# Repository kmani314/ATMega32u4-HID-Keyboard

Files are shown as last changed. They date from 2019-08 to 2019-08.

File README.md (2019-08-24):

## ATMega32u4 HID Keyboard
###### Board Project 2019 - Krishna Mani
This is software for ATMega32u4 or compatible AVR hardware USB chips that implements a standard-complying HID keyboard using only AVR-LIBC.

I used these for reference when coding:

1. https://www.avrfreaks.net/forum/usb-initialization-problem
2. https://www.pjrc.com/teensy/usb_keyboard.html
3. https://www.usb.org/sites/default/files/documents/hid1_11.pdf
4. https://www.avrfreaks.net/forum/help-properly-initializing-usb-hardware-atmega32u4
5. https://www.beyondlogic.org/usbnutshell/usb1.shtml
6. http://ww1.microchip.com/downloads/en/devicedoc/atmel-7766-8-bit-avr-atmega16u4-32u4_datasheet.pdf
7. https://github.com/arduino/ArduinoCore-avr/blob/master/cores/arduino/USBCore.cpp
8. http://sdphca.ucsd.edu/lab_equip_manuals/usb_20.pdf

Finished Board:

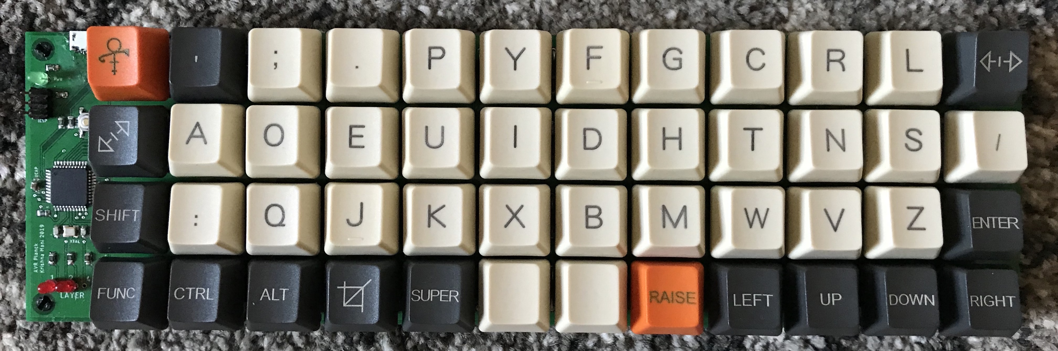
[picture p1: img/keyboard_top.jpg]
Finished Board


### Hardware

##### Microcontroller
The ATMega32u4 controls the scanning matrix and the USB interface. I chose it because of its hardware USB interface and because it has enough I/O pins to support the whole keyboard without needing any multiplexing. It also has enough flash and SRAM for storing layouts. The 32u4 on the keyboard runs at 16mHz from an external crystal oscillator with 22pF load capacitors. It is powered directly from the USB lines with filtering capacitors.
##### PCBs
Initially, I needed to test the main microcontroller circuit of the keyboard to ensure that it worked and that the USB worked, because I had developed on an Arduino Leonardo. (boards/ATMegaTestingBoard.brd)

##### ATMega32u4 Circuit
The portion of the board for the ATMega32u4 is fairly standard for this chip and is similar to the Arduino Leonardo, excluding the power regulators. It consists of the chip, the oscillator and load caps, the power and layer leds, the reset switch, the USB connector and data resistors, the ICSP pins, and the filtering caps on the underside of the board.

Top / Bottom (boards/Keyboard.brd):

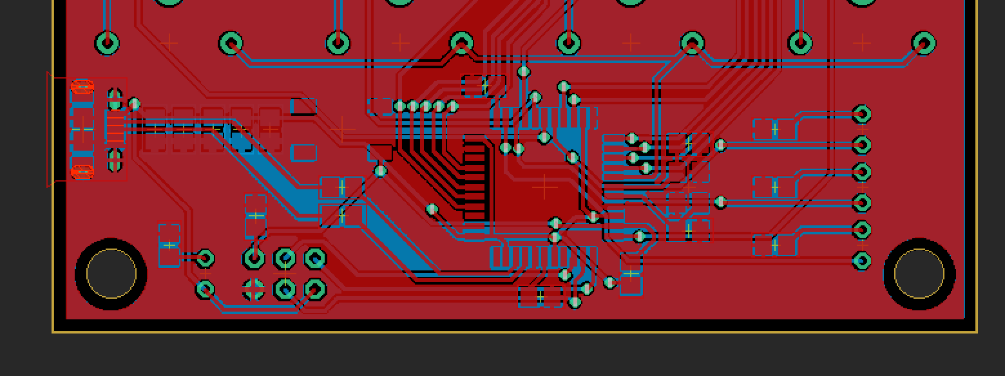
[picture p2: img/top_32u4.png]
32u4 Top


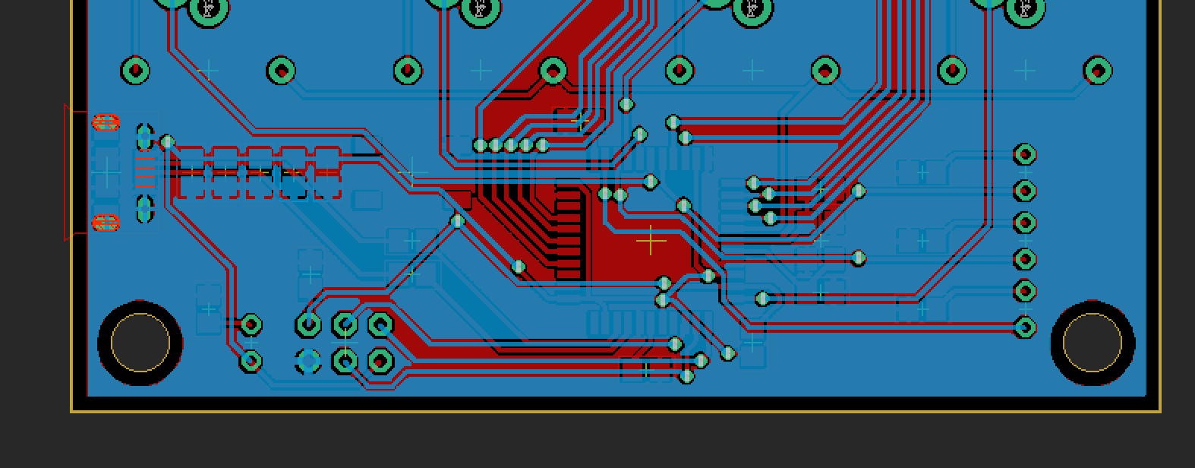
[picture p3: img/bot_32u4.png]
32u4 Bottom


The rest of the board is the scanning matrix. The rows and columns use up the majority of the I/O on the chip.
The matrix is standard for a keyboard - one pin of each switch in a column is connected through a diode to every other one in the column. Then, the remaining pin in each switch is common with the row. I used through hole diodes because they are much easier to solder. The switches are standard mechanical keyboard switches, and the footprints are from here: https://github.com/mknyszek/gateron-eagle
To read the matrix, the row pins are pulled high through internal pull-up resistors. One column at a time is set low, so that a pressed key would pull the row pin low, signaling a key press at the current row and column index.

Top / Bottom matrix (boards/Keyboard.brd):

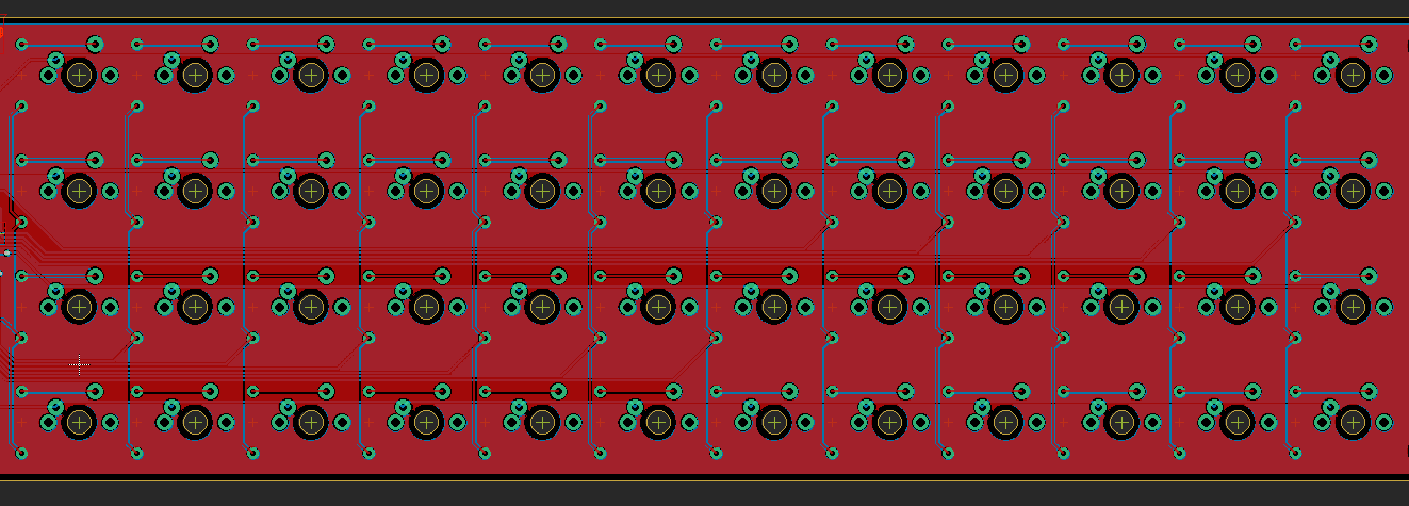
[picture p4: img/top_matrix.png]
Matrix Top


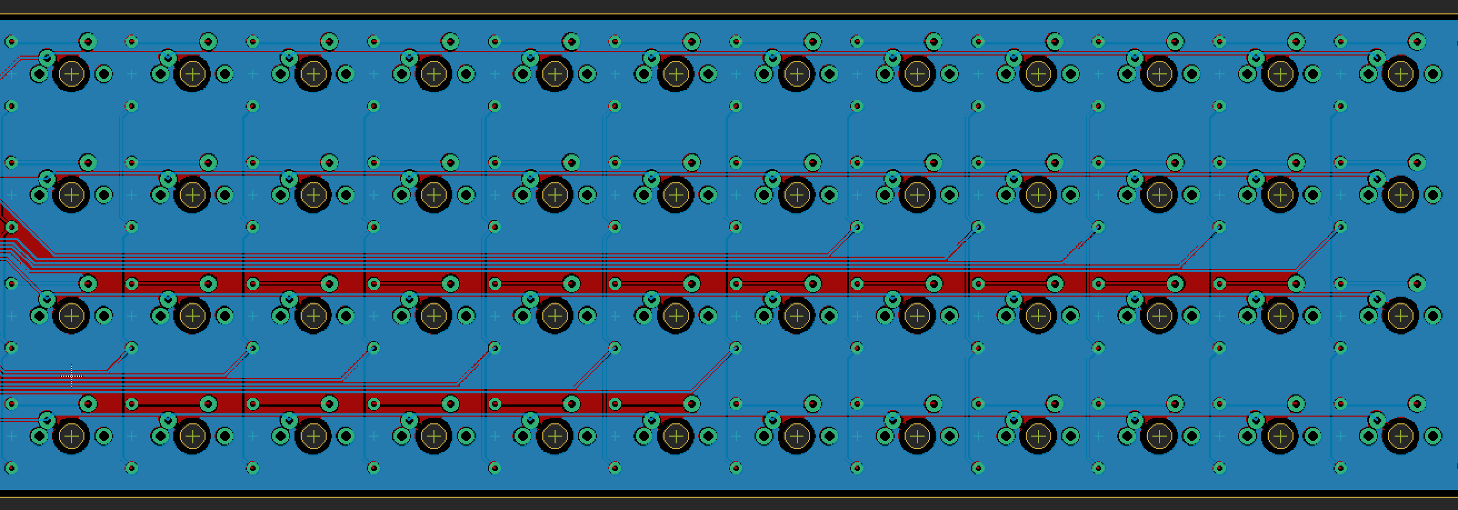
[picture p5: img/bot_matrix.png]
Matrix Bottom


##### Board Assembly
Assembling the board was straightforward except for the SMD components, specifically the TQFP ATMega32u4. It is really easy to bridge several pads very quickly, and completely ruin the chip. I soldered these by holding them in place and tacking down the corners so the chip didn’t move. I used a lot of flux, then with very little solder dragged the iron across the pins. The USB connector is also really difficult, I soldered the anchor pins and then the pins. It is really easy to bridge the pins with the ground enclosure. Using super glue after ensures that the connector doesn’t snap off when you unplug the cable.

### Code
##### USB
First, the USB controller of the 32u4 is initialized. This is handled in the function `usb_init()`. The PLL (Phase Locked Loop) is initialized, taking the external clock as input. It runs at 48mHz and acts as the USB clock. After the USB controller is initialized, the control endpoint is set up and will receive setup packets from the host. The setup packets, handled in the ISR `USB_gen_vect`, elicit responses from the keyboard based on the values of bmRequestType and bRequest, which determine the type of request. After the host has requested and received the USB descriptors, and the keyboard has correctly responded to HID-specific requests, the host can enumerate the device and use it as an input device.

The key repeat feature of modern keyboards is handled separately from the standard functions `usb_send()` and `usb_send_keypress()`. If a key is held down for some period of time, it should be repeated until it is released. This is taken care of in the ISR `USB_gen_vect`, specifically when the SOFE (start of frame) bit is set. This interrupt triggers at 1kHz, which is how often the host sends start of frame packets. If no keypresses have been generated since the period time, which is kept track of with keyboard_idle_value and current_idle, the entire HID report is resent to facilitate key repeat. The period of time the device should wait before resending the report is set from the wValue in the HID request SET_IDLE.
##### Matrix Software
The scanning matrix of the keyboard uses the current sourcing and internal pullups of the I/O ports on the 32u4. Because of the orientation of the diodes, the columns of the keyboard are set low when they are going to be read. The rows are always pulled up, meaning that if a key is pressed, it will be pulled low because the switch is connecting the row and columns. The matrix scanning is repeated quickly, and changes in key state are recorded in the six-byte USB HID report. The report is six bytes to support six concurrent key presses. The keyboard dynamically assigns and removes keys from the report to support 6-key-rollover, and it also resets the reports on layout layer shifts to prevent strange glitches. The meta and special keys like CTRL, ALT, and SHIFT have their own byte apart from the report, where each bit represents a different key. This is according to the USB HID Spec.

The rows and columns of the recorded keypresses are translated into actual keycodes from the specified layout in `layout.h`. The layout is written from the standard HID keycodes in `keys.h`. Because the keyboard does not have enough physical keys to support all the letters, function, and number keys, some keys are macros that change the mappings of all the keys. These keys are handled separately and do not generate keypress events on their own. Rather, they update the current layer that the scanning matrix is reporting keypresses from to change the keycodes.
### Improvements
1. Changing the routing on PORTD to make it iterable, making the code more readable and cleaner.
2. Using USB-C instead of micro b, meaning that you would not need a dongle for use with newer macs. This would, however, make it much more difficult to solder and the PCB more complicated, since the USB-C connectors have 24 pins.
3. Using the BGA package for the ATMega32u4 so that it could fit in between switches on the underside of the board, meaning that the PCB would only have to be as big as to fit the switches. This would make it more compact.
4. Using symmetrical keycaps so that the keycaps aren’t skewed when using keyboard layouts other than QWERTY.
5. Adding support for a dedicated FN key endpoint and Caps lock and num lock; currently you have to remap function to media keys with a third party tool for the media keys on the keyboard to work on touch bar macs.
6. Move the ICSP connector down, right now you have to bend the power LED up for the connector to make contact with the headers.
7. Route the third layer led to a different I/O port, right now only two of the three LEDs work.

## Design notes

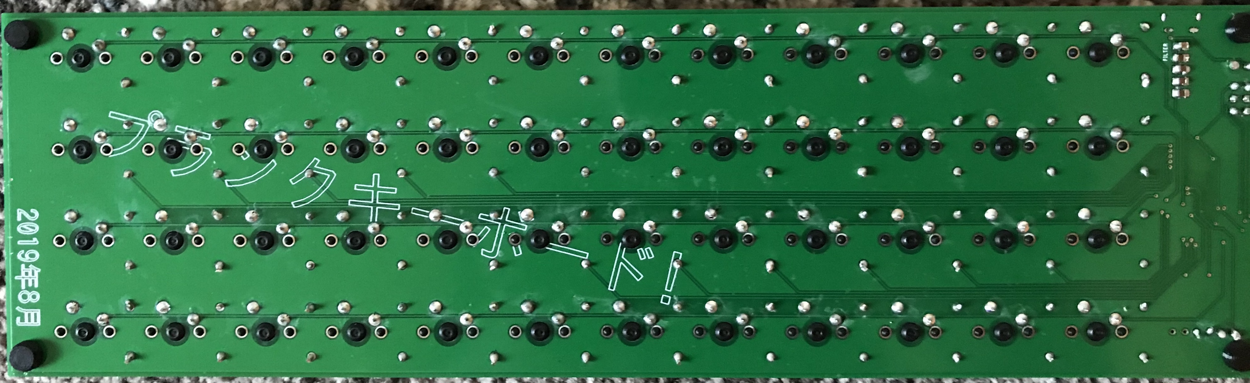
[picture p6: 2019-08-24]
img/keyboard_bot.jpg

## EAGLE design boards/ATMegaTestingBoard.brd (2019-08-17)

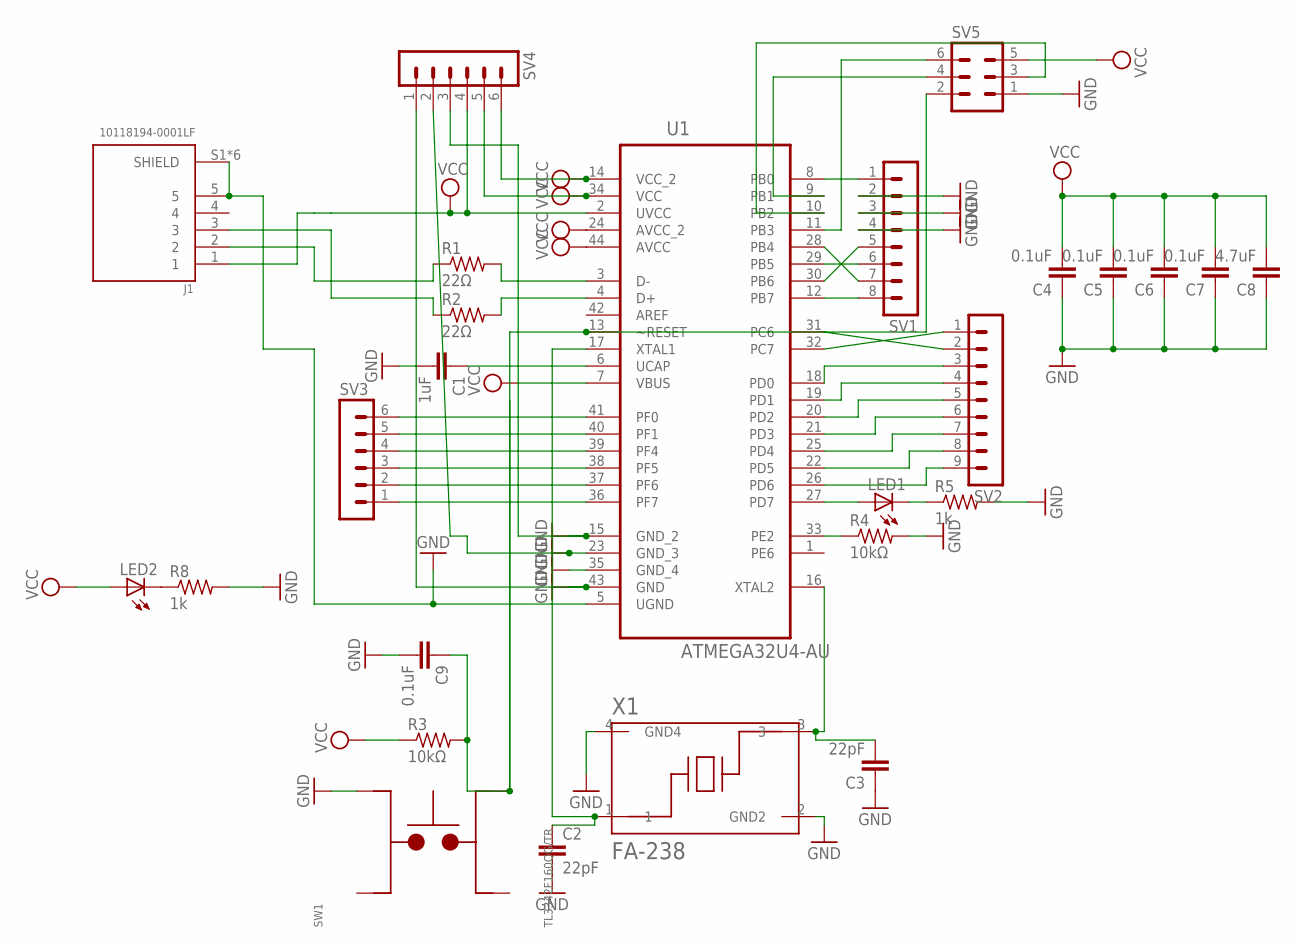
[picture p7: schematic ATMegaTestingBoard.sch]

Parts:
C1: 1uF; C0805
C2, C3: 22pF; C0805
C4, C5, C6, C7, C9: 0.1uF; C0805
C8: 4.7uF; C0805
J1: 10118194-0001LF; AMPHENOL_10118194-0001LF
LED1, LED2: LEDCHIPLED_0805; CHIPLED_0805
R1, R2: 22Ω; R0805
R3, R4: 10kΩ; R0805
R5, R8: 1k; R0805
SV1: MA08-1
SV2: MA09-1
SV3, SV4: MA06-1
SV5: MA03-2
SW1: TL3342F160QG/TR; SW_TL3342F160QG/TR
U1: ATMEGA32U4-AU; QFP80P1200X1200X120-44N
X1: FA-238; OSCCC320X250X70-4N

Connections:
GND: C1.2, C2.2, C3.1, C4.1, C5.1, C6.1, C7.1, C8.1, C9.2, J1.5, J1.S1 (SHIELD), J1.S2 (SHIELD), J1.S3 (SHIELD), J1.S4 (SHIELD), J1.S5 (SHIELD), J1.S6 (SHIELD), R4.2, R5.2, R8.2, SV1.2, SV1.3, SV1.4, SV4.1, SV4.2, SV4.3, SV5.1, SW1.4, U1.5 (UGND), U1.15 (GND_2), U1.23 (GND_3), U1.35 (GND_4), U1.43 (GND), X1.2 (GND2), X1.4 (GND4)
unnamed: R1.2, U1.3 (D-)
unnamed: J1.3, R2.1
unnamed: J1.2, R1.1
unnamed: C1.1, U1.6 (UCAP)
unnamed: R2.2, U1.4 (D+)
unnamed: SV1.1, U1.8 (PB0)
unnamed: C9.1, R3.2, SV5.2, SW1.2, U1.13 (~RESET)
unnamed: C2.1, U1.17 (XTAL1), X1.1
unnamed: R4.1, U1.33 (PE2)
unnamed: C3.2, U1.16 (XTAL2), X1.3
unnamed: LED1.A, U1.27 (PD7)
unnamed: LED1.C, R5.1
unnamed: SV1.7, U1.28 (PB4)
unnamed: SV1.5, U1.30 (PB6)
unnamed: LED2.C, R8.1
unnamed: SV5.6, U1.11 (PB3)
unnamed: SV5.4, U1.9 (PB1)
unnamed: SV5.3, U1.10 (PB2)
unnamed: SV1.6, U1.29 (PB5)
unnamed: SV2.2, U1.31 (PC6)
unnamed: SV2.1, U1.32 (PC7)
unnamed: SV1.8, U1.12 (PB7)
unnamed: SV2.3, U1.18 (PD0)
unnamed: SV2.4, U1.19 (PD1)
unnamed: SV2.5, U1.20 (PD2)
unnamed: SV2.6, U1.21 (PD3)
unnamed: SV2.7, U1.25 (PD4)
unnamed: SV2.8, U1.22 (PD5)
unnamed: SV2.9, U1.26 (PD6)
unnamed: SV3.6, U1.41 (PF0)
unnamed: SV3.5, U1.40 (PF1)
unnamed: SV3.4, U1.39 (PF4)
unnamed: SV3.3, U1.38 (PF5)
unnamed: SV3.2, U1.37 (PF6)
unnamed: SV3.1, U1.36 (PF7)
VCC: C4.2, C5.2, C6.2, C7.2, C8.2, J1.1, LED2.A, R3.1, SV4.4, SV4.5, SV4.6, SV5.5, U1.2 (UVCC), U1.7 (VBUS), U1.14 (VCC_2), U1.24 (AVCC_2), U1.34 (VCC), U1.44 (AVCC)

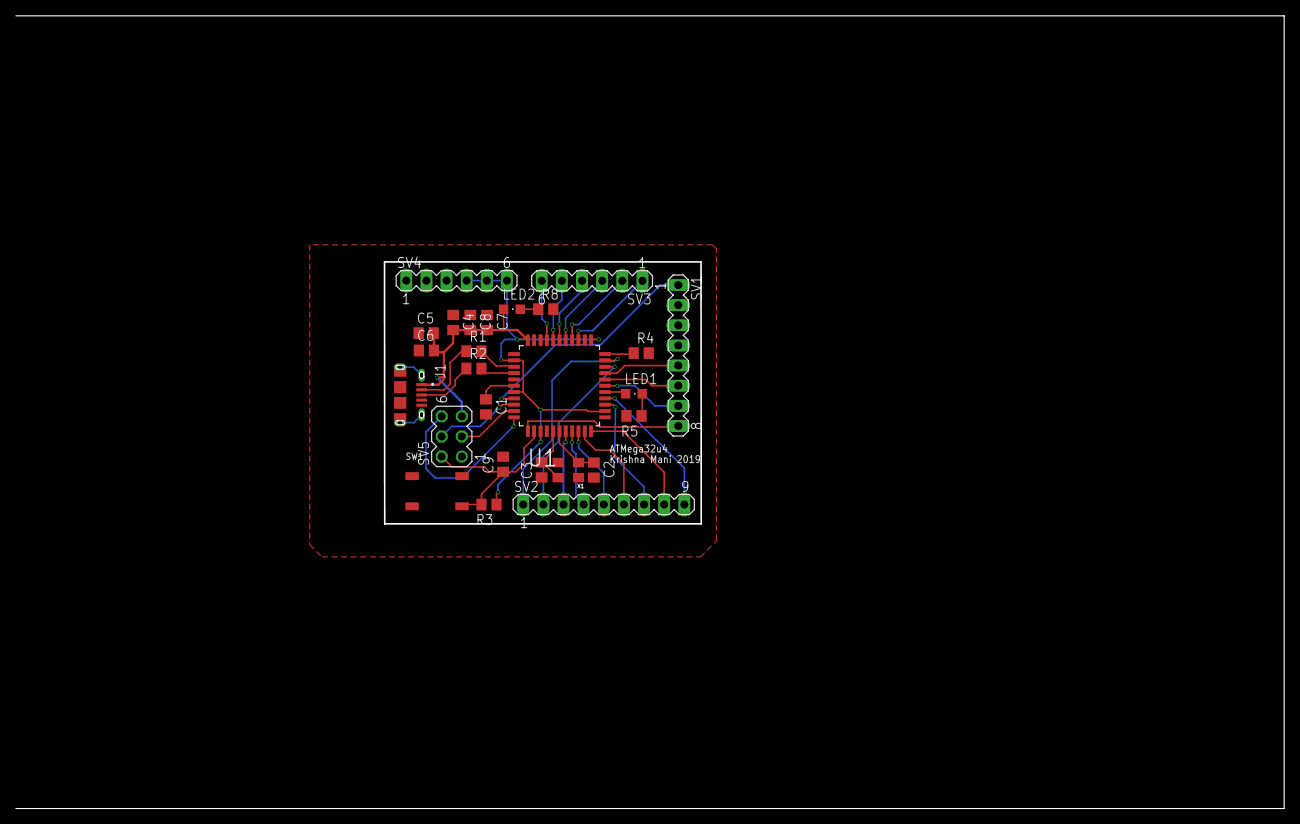
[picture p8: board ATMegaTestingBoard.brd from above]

Board: 2 copper layers, 160.0 x 100.0 mm, 26 parts (0 on the bottom side), 37 nets.

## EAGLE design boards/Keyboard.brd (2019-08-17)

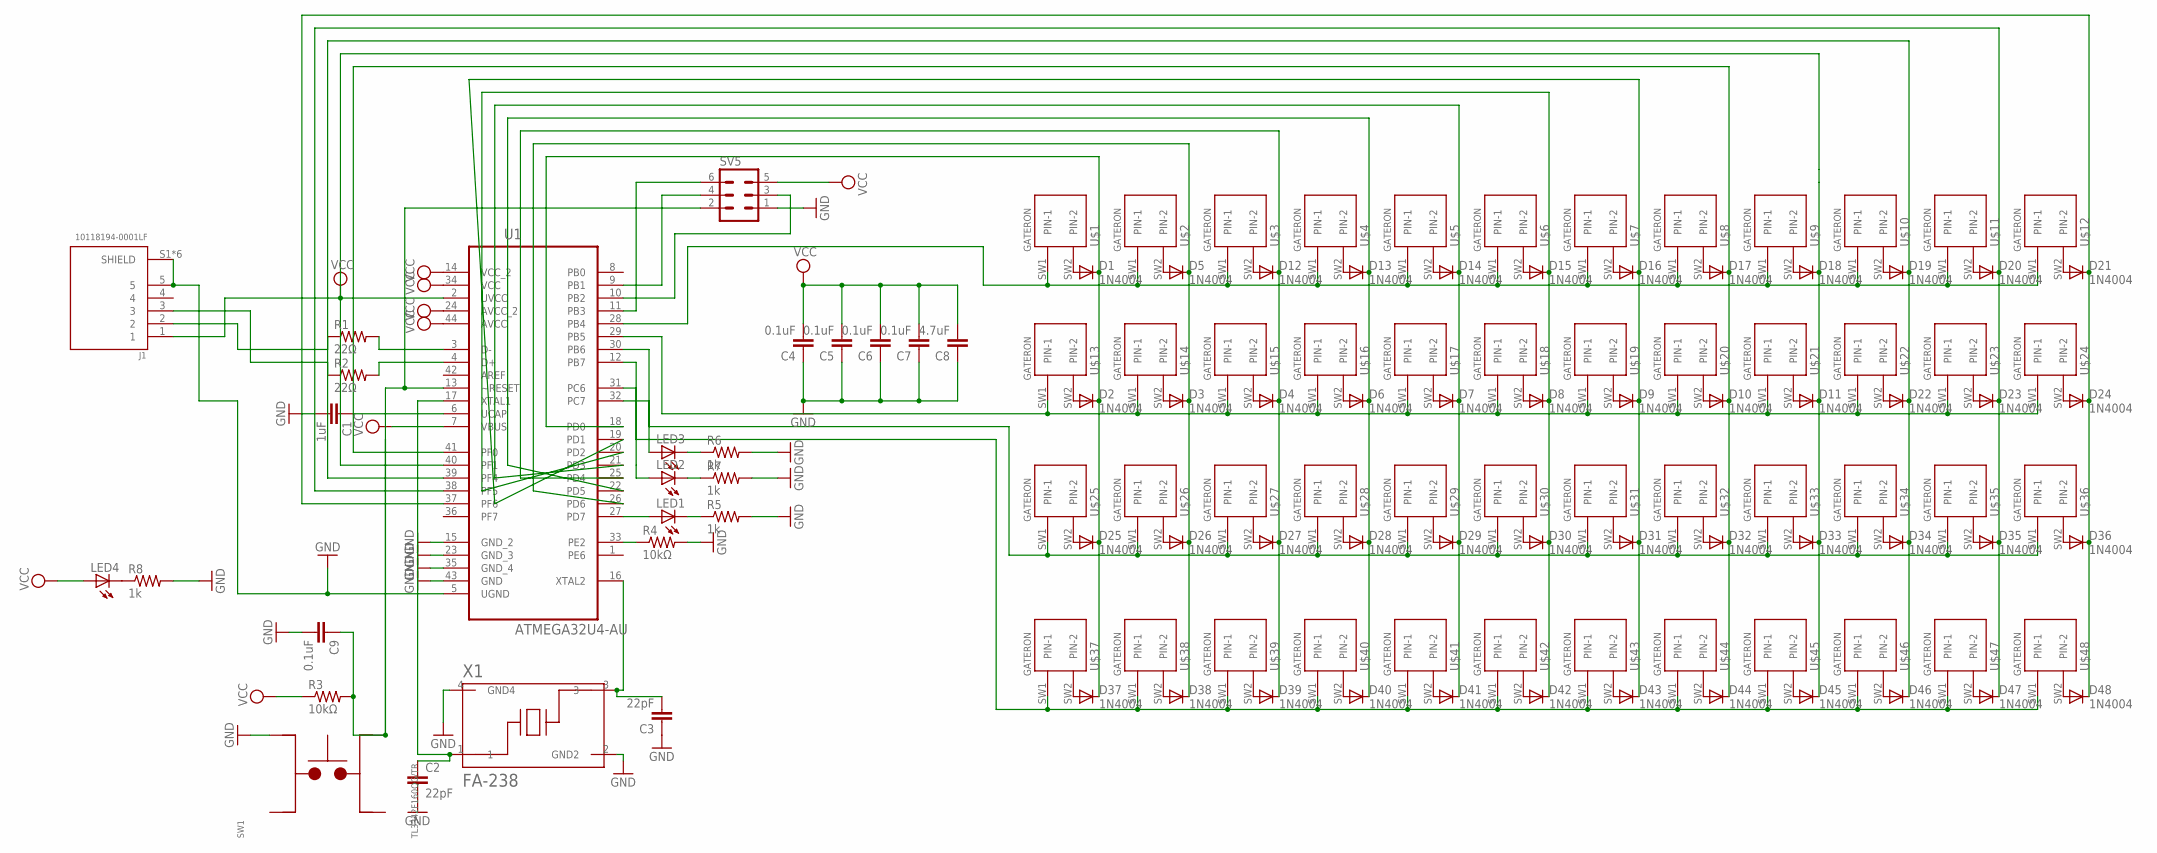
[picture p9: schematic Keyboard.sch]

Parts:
C1: 1uF; C0805
C2, C3: 22pF; C0805
C4, C5, C6, C7, C9: 0.1uF; C0805
C8: 4.7uF; C0805
D1, D2, D3, D4, D5, D6, D7, D8, D9, D10, D11, D12, D13, D14, D15, D16, D17, D18, D19, D20, D21, D22, D23, D24, D25, D26, D27, D28, D29, D30, D31, D32, D33, D34, D35, D36, D37, D38, D39, D40, D41, D42, D43, D44, D45, D46, D47, D48: 1N4004; DO41-10
J1: 10118194-0001LF; AMPHENOL_10118194-0001LF
LED1, LED2, LED3, LED4: LED_ELD260; LED_LD260
R1, R2: 22Ω; R0805
R3, R4: 10kΩ; R0805
R5, R6, R7, R8: 1k; R0805
SV5: MA03-2
SW1: TL3342F160QG/TR; SW_TL3342F160QG/TR
U1: ATMEGA32U4-AU; QFP80P1200X1200X120-44N
U$1, U$2, U$3, U$4, U$5, U$6, U$7, U$8, U$9, U$10, U$11, U$12, U$13, U$14, U$15, U$16, U$17, U$18, U$19, U$20, U$21, U$22, U$23, U$24, U$25, U$26, U$27, U$28, U$29, U$30, U$31, U$32, U$33, U$34, U$35, U$36, U$37, U$38, U$39, U$40, U$41, U$42, U$43, U$44, U$45, U$46, U$47, U$48: GATERON
X1: FA-238; OSCCC320X250X70-4N

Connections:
GND: C1.2, C2.2, C3.1, C4.1, C5.1, C6.1, C7.1, C8.1, C9.2, J1.5, J1.S1 (SHIELD), J1.S2 (SHIELD), J1.S3 (SHIELD), J1.S4 (SHIELD), J1.S5 (SHIELD), J1.S6 (SHIELD), R4.2, R5.2, R6.2, R7.2, R8.2, SV5.1, SW1.4, U1.5 (UGND), U1.15 (GND_2), U1.23 (GND_3), U1.35 (GND_4), U1.43 (GND), X1.2 (GND2), X1.4 (GND4)
unnamed: R1.2, U1.3 (D-)
unnamed: J1.3, R2.1
unnamed: J1.2, R1.1
unnamed: C1.1, U1.6 (UCAP)
unnamed: R2.2, U1.4 (D+)
unnamed: U1.28 (PB4), U$1.SW1 (PIN-1), U$2.SW1 (PIN-1), U$3.SW1 (PIN-1), U$4.SW1 (PIN-1), U$5.SW1 (PIN-1), U$6.SW1 (PIN-1), U$7.SW1 (PIN-1), U$8.SW1 (PIN-1), U$9.SW1 (PIN-1), U$10.SW1 (PIN-1), U$11.SW1 (PIN-1), U$12.SW1 (PIN-1)
unnamed: C9.1, R3.2, SV5.2, SW1.2, U1.13 (~RESET)
unnamed: C2.1, U1.17 (XTAL1), X1.1
unnamed: R4.1, U1.33 (PE2)
unnamed: C3.2, U1.16 (XTAL2), X1.3
unnamed: LED1.A, U1.27 (PD7)
unnamed: LED1.K (C), R5.1
unnamed: U1.29 (PB5), U$13.SW1 (PIN-1), U$14.SW1 (PIN-1), U$15.SW1 (PIN-1), U$16.SW1 (PIN-1), U$17.SW1 (PIN-1), U$18.SW1 (PIN-1), U$19.SW1 (PIN-1), U$20.SW1 (PIN-1), U$21.SW1 (PIN-1), U$22.SW1 (PIN-1), U$23.SW1 (PIN-1), U$24.SW1 (PIN-1)
unnamed: D2.A, U$13.SW2 (PIN-2)
unnamed: LED4.K (C), R8.1
unnamed: SV5.6, U1.11 (PB3)
unnamed: SV5.4, U1.9 (PB1)
unnamed: SV5.3, U1.10 (PB2)
unnamed: D3.A, U$14.SW2 (PIN-2)
unnamed: D1.A, U$1.SW2 (PIN-2)
unnamed: D4.A, U$15.SW2 (PIN-2)
unnamed: D6.A, U$16.SW2 (PIN-2)
unnamed: D7.A, U$17.SW2 (PIN-2)
unnamed: D5.A, U$2.SW2 (PIN-2)
unnamed: D8.A, U$18.SW2 (PIN-2)
unnamed: D9.A, U$19.SW2 (PIN-2)
unnamed: D10.A, U$20.SW2 (PIN-2)
unnamed: D11.A, U$21.SW2 (PIN-2)
unnamed: D22.A, U$22.SW2 (PIN-2)
unnamed: D23.A, U$23.SW2 (PIN-2)
unnamed: D12.A, U$3.SW2 (PIN-2)
unnamed: D13.A, U$4.SW2 (PIN-2)
unnamed: D14.A, U$5.SW2 (PIN-2)
unnamed: D15.A, U$6.SW2 (PIN-2)
unnamed: D16.A, U$7.SW2 (PIN-2)
unnamed: D17.A, U$8.SW2 (PIN-2)
unnamed: D18.A, U$9.SW2 (PIN-2)
unnamed: D19.A, U$10.SW2 (PIN-2)
unnamed: D20.A, U$11.SW2 (PIN-2)
unnamed: D21.A, U$12.SW2 (PIN-2)
unnamed: D24.A, U$24.SW2 (PIN-2)
unnamed: U1.30 (PB6), U$25.SW1 (PIN-1), U$26.SW1 (PIN-1), U$27.SW1 (PIN-1), U$28.SW1 (PIN-1), U$29.SW1 (PIN-1), U$30.SW1 (PIN-1), U$31.SW1 (PIN-1), U$32.SW1 (PIN-1), U$33.SW1 (PIN-1), U$34.SW1 (PIN-1), U$35.SW1 (PIN-1), U$36.SW1 (PIN-1)
unnamed: D25.A, U$25.SW2 (PIN-2)
unnamed: D26.A, U$26.SW2 (PIN-2)
unnamed: D27.A, U$27.SW2 (PIN-2)
unnamed: D28.A, U$28.SW2 (PIN-2)
unnamed: D29.A, U$29.SW2 (PIN-2)
unnamed: D30.A, U$30.SW2 (PIN-2)
unnamed: D31.A, U$31.SW2 (PIN-2)
unnamed: D32.A, U$32.SW2 (PIN-2)
unnamed: D33.A, U$33.SW2 (PIN-2)
unnamed: D34.A, U$34.SW2 (PIN-2)
unnamed: D35.A, U$35.SW2 (PIN-2)
unnamed: D36.A, U$36.SW2 (PIN-2)
unnamed: U1.12 (PB7), U$37.SW1 (PIN-1), U$38.SW1 (PIN-1), U$39.SW1 (PIN-1), U$40.SW1 (PIN-1), U$41.SW1 (PIN-1), U$42.SW1 (PIN-1), U$43.SW1 (PIN-1), U$44.SW1 (PIN-1), U$45.SW1 (PIN-1), U$46.SW1 (PIN-1), U$47.SW1 (PIN-1), U$48.SW1 (PIN-1)
unnamed: D37.A, U$37.SW2 (PIN-2)
unnamed: D38.A, U$38.SW2 (PIN-2)
unnamed: D39.A, U$39.SW2 (PIN-2)
unnamed: D40.A, U$40.SW2 (PIN-2)
unnamed: D41.A, U$41.SW2 (PIN-2)
unnamed: D42.A, U$42.SW2 (PIN-2)
unnamed: D43.A, U$43.SW2 (PIN-2)
unnamed: D44.A, U$44.SW2 (PIN-2)
unnamed: D45.A, U$45.SW2 (PIN-2)
unnamed: D46.A, U$46.SW2 (PIN-2)
unnamed: D47.A, U$47.SW2 (PIN-2)
unnamed: D48.A, U$48.SW2 (PIN-2)
unnamed: D1.C, D2.C, D25.C, D37.C, U1.18 (PD0)
unnamed: D3.C, D5.C, D26.C, D38.C, U1.26 (PD6)
unnamed: D4.C, D12.C, D27.C, D39.C, U1.25 (PD4)
unnamed: D6.C, D13.C, D28.C, D40.C, U1.22 (PD5)
unnamed: D7.C, D14.C, D29.C, D41.C, U1.21 (PD3)
unnamed: D8.C, D15.C, D30.C, D42.C, U1.20 (PD2)
unnamed: D9.C, D16.C, D31.C, D43.C, U1.19 (PD1)
unnamed: D10.C, D17.C, D32.C, D44.C, U1.41 (PF0)
unnamed: D11.C, D18.C, D33.C, D45.C, U1.40 (PF1)
unnamed: D19.C, D22.C, D34.C, D46.C, U1.39 (PF4)
unnamed: D20.C, D23.C, D35.C, D47.C, U1.38 (PF5)
unnamed: D21.C, D24.C, D36.C, D48.C, U1.37 (PF6)
unnamed: LED3.K (C), R6.1
unnamed: LED2.K (C), R7.1
unnamed: LED2.A, U1.31 (PC6)
unnamed: LED3.A, U1.32 (PC7)
VCC: C4.2, C5.2, C6.2, C7.2, C8.2, J1.1, LED4.A, R3.1, SV5.5, U1.2 (UVCC), U1.7 (VBUS), U1.14 (VCC_2), U1.24 (AVCC_2), U1.34 (VCC), U1.44 (AVCC)

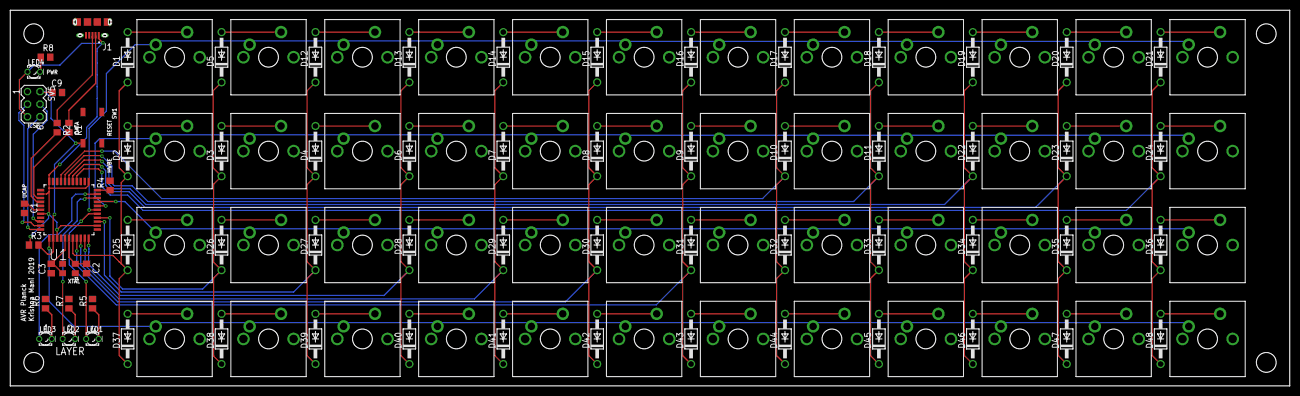
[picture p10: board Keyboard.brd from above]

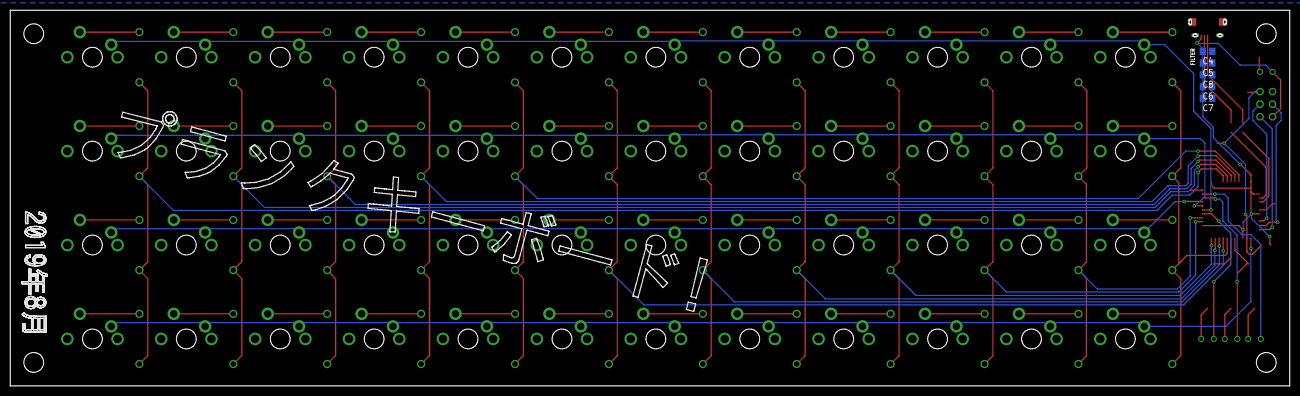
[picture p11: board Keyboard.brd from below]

Board: 2 copper layers, 258.9 x 76.0 mm, 122 parts (5 on the bottom side), 85 nets.

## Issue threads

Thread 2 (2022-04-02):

Wrong register

lucasperovani, 2022-04-02:
Hi, you made an excellent repository with a bunch of hard-to-find knowledge based on the USB of atmega32u4. I think, and hope, you still wanna improve it... I found a silly mistake that is easy to pass over and is easy to fix.

In function usb_init (src/usb.c) UDCON is setted to 0. But the DETACH bit is cleared in USBCON. It doesn't impact the functionality of the code (unless you need the VBUS Transition Interrupt).

```
...
USBCON &= ~(1 << FRZCLK);          // Unfreeze the clock

  UDCON = 0;  // FULL SPEED MODE

  USBCON &= ~(1 << DETACH);  // Connect  <- Bit DETACH being cleared in USBCON, but it was cleared in UDCON
  UDIEN |= (1 << EORSTE) |
           (1 << SOFE);  // Re-enable the EORSTE (End Of Reset) Interrupt so we
                         // know when we can configure the control endpoint
...

```

The line `USBCON &= ~(1 << DETACH);` can be easily removed without any error in the code (I think).

The pages in the [manual](https://ww1.microchip.com/downloads/en/DeviceDoc/Atmel-7766-8-bit-AVR-ATmega16U4-32U4_Datasheet.pdf) that specifies those registers are 267, for USBCON, and 281, for UDCON. I couldn't test it yet, btw.
Nevertheless, I'm grateful for your job and want to thank you! It's pretty hard to find those information in Google!!

YellowKll, 2022-12-15:
I was going  to report the same "issue".
DETACH doesn't belong to USBCON, but it belongs to UDCON.

kmani314, 2022-12-18:
No longer have hardware to test this on, but I think you're right based on the datasheet. Thanks!

Closed 2022-12-18.

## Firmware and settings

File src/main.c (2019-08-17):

/*
main.c
*/

#define F_CPU 16000000

#include <avr/io.h>
#include <string.h>
#include <util/delay.h>
#include "matrix.h"
#include "usb.h"

int main(int argc, char** argv) {
  usb_init();

  DDRC |= ((1 << 7) | (1 << 6));

  while (!get_usb_config_status()) {
    // LED Animation
    PORTC &= ~(1 << 6);
    PORTC |= (1 << 7);
    _delay_ms(100);
    PORTC &= ~(1 << 7);
    PORTC |= (1 << 6);
    _delay_ms(100);
  }
  PORTC &= ~((1 << 6) | (1 << 7));

  matrix_init();
	while(1) do_matrix_scan(); // Scan the matrix
}

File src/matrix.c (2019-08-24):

/*
 * matrix.c
 */
#include "matrix.h"
#include "layout.h"
#include "usb.h"
#include <avr/interrupt.h>
#include <avr/io.h>
#include <avr/pgmspace.h>
#include <stdbool.h>
#include <util/delay.h>

int layout_num = 0;
bool has_unsent_packets = false;

bool state_layer[NUM_ROWS][NUM_COLS] = {
    {1, 1, 1, 1, 1, 1, 1, 1, 1, 1, 1, 1},
    {1, 1, 1, 1, 1, 1, 1, 1, 1, 1, 1, 1},
    {1, 1, 1, 1, 1, 1, 1, 1, 1, 1, 1, 1},
    {1, 1, 1, 1, 1, 1, 1, 1, 1, 1, 1, 1}};  // Key States to do state changes

void matrix_init() {
  DDRD = 0xFF;   // Configure the first 7 rows as outputs
  DDRF = 0xFF;   // Configure the last 5 as outputs
  PORTF = 0xFF;  // The logic is inverted, being pulled low is a keypress
  PORTD = 0xFF;

  DDRB &= 0;     // Configure the row port as inputs
  PORTB = 0xFF;  // Enable the Pull up resistors

  TCCR0B |= (1 << CS00) | (1 << CS02); // Set up the 1024 prescaler on timer 0
  TCCR0A = (1 << WGM01); // Set the timer to compare mode
  OCR0A = 255; // Set the compare value to max for a lower frequency
  TIMSK0 = (1 << OCIE0A); // Enable timer compare interrupts
}

void do_layer_led() { PORTC = layout_num << 6; }

void do_matrix_scan() {
  bool key_state;

  for (int i = 0; i < NUM_ROWS; i++) {
		_delay_ms(10);
		for (int j = 0; j < NUM_COLS; j++) {
			_delay_ms(10);
			if (j < 7) {
        // This is because of the dumb routing on PORTD
        int DNUM;
        switch (j) {
          case (0):
            DNUM = 0;
            break;
          case (1):
            DNUM = 6;
            break;
          case (2):
            DNUM = 4;
            break;
          case (3):
            DNUM = 5;
            break;
          case (4):
            DNUM = 3;
            break;
          case (5):
            DNUM = 2;
            break;
          case (6):
            DNUM = 1;
            break;
        }

        PORTD &= ~(1 << DNUM);  // Set it low to read from the row
      } else {  // PORTF is not continuous, which means we cannot just loop over
                // it
        int FNUM = j - 7;
        if (FNUM > 1) FNUM += 2;  // Bits 2 and 3 do not exist on PORTF
        PORTF &= ~(1 << FNUM);
      }
			cli(); // Turn off interrupts for this section
      if ((bool)(PINB & (1 << (i + B_OFFSET))) !=
          state_layer[i][j]) { // Is the value in the state array different from the value read from the key?
       	 
				if (!(PINB & (1 << (i + B_OFFSET)))) {  // Low to High (Key Down)
					uint16_t key = layout[layout_num][i][j];
          if (key & KEY_MOD_MACRO) { // Is this a macro key, in which case we have to set the appropriate value in the modifier bit
            key &= ~(KEY_MOD_MACRO);
            keyboard_modifier |= key;

          } else if (key & KEY_LS_MACRO) { // Is this a layer shift macro, in which case we have to change the layer number
            key &= ~(KEY_LS_MACRO);
            if ((layout_num | key) <= (NUM_LAYERS - 1)) { // Make sure we're not shifting to a layer that doesn't exist
              layout_num |= key;
              do_layer_led(); // Set the layer LEDs
              for (int k = 0; k < 6; k++) {
                keyboard_pressed_keys[k] = 0; // We have to clear the report after shifting layers because of conflicts from key-ups and key-downs on different layers
              }
            }
          } else { // This is just a normal keypress, record it in the first available slot in the HID report 
            for (int k = 0; k < 6; k++) {
							if (keyboard_pressed_keys[k] == 0) { // '0' is the code for no key press
								keyboard_pressed_keys[k] = key; 
								break;
              }
            }
          }
        } else { // Handle key up events
          uint16_t key = layout[layout_num][i][j];
          if (key & KEY_MOD_MACRO) { // Is this a macro key, we have to remove the macro bit from the modifier byte to signify a key up
            key &= ~(KEY_MOD_MACRO);
            keyboard_modifier &= ~(key);

          } else if (key & KEY_LS_MACRO) { // Is this a layer shift key, we have to remove the bit from layout_num to switch back to the previous layer
            key &= ~(KEY_LS_MACRO);
            for (int k = 0; k < 6; k++) {
              keyboard_pressed_keys[k] = 0; // Clear the HID report
            }
            layout_num &= ~(key);
            do_layer_led();
          } else {
            for (int k = 0; k < 6; k++) { // Normal key up event, find the key in the HID report and remove it
              if (keyboard_pressed_keys[k] == key) {
								keyboard_pressed_keys[k] = 0;
              }
            }
          }
        }
        state_layer[i][j] =
            (bool)(PINB & (1 << (i + B_OFFSET)));  // Record the changed state in the array to register future state changes
        has_unsent_packets = true; // Let the timer interrupt know that we've got some packets to be sent
      }
			sei(); // Re-enable the interrupts
    	PORTF = 0xFF; // Set all the pins high to not generate false keypresses when scanning future columns
			PORTD = 0xFF; 

		}
  }
}

ISR(TIMER0_COMPA_vect) { // The USB packets are sent on a timer interrupt because OSX was showing strange USB keypress rejection errors due to high USB packet frequency
  if (has_unsent_packets) {
    usb_send();
		has_unsent_packets = false;
  }
}

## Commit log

2019-07-26 Add working device enumeration
2019-07-26 Working Device, Configuration, Interface, Endpoint Enumeration. Need to work on HID class-specific request handling
2019-07-27 Basic keypresses work, need to fix key repeat. Problem was GET_STATUS condition had = instead of ==, didn't notice for 6 hours
    [main.c]
2019-07-29 Add full ASCII, fix repeat glitch, add keys.h, fix timeout issue
    [main.c]
2019-08-14 Works fully, still some minor glitches to fix
    [matrix.c]
2019-08-14 0.1 Finished, I haven't found anything that's broken yet
    [matrix.c]
2019-08-14 fixed some glitches, works better now
    [main.c, matrix.c]
2019-08-14 Add post build script to cmake, add interval usb throttling to fix os rejection, changed my layout
    [matrix.c]
2019-08-17 fixed random key glitch bug, change my layout. fully working now
    [main.c, matrix.c]
2019-08-17 Work on writeup, add board files
    [ATMegaTestingBoard.brd, ATMegaTestingBoard.sch, Keyboard.brd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]
2019-08-24 fix return types for matrix functions
    [matrix.c]
